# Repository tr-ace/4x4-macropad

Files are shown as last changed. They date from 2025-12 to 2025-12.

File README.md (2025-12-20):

# 4x4 Macropad

The Macropad is a 16-key keyboard with assignable keys via Python and the KMK library. The microcontroller uses the CircuitPython firmware.

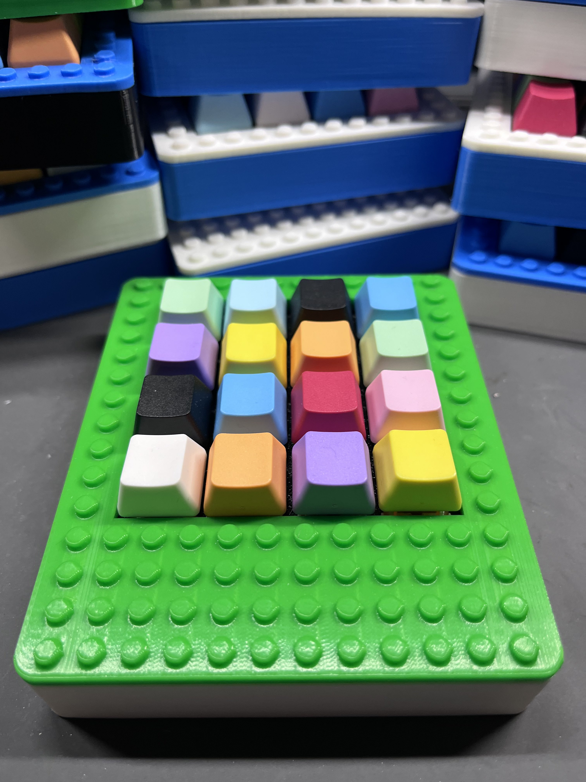
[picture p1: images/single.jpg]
Macropad


## Usage

Plug the Macropad into your PC with a USB C cable. Windows Explorer may open, since the CircuitPython firmware on the microcontroller may be detected as a mass storage device. You can close Windows Explorer, unless you'd like to customize the keymap.

## Default Keymap

> ℹ️ **Info**
> Row 1, Column 1 is the key closest to the USB C port)

| Row \ Col | Col 1 | Col 2 | Col 3 | Col 4 |
| --- | --- | --- | --- | --- |
| **Row 1** | Ctrl + A<br>(Select All) | Ctrl + C<br>(Copy) | Ctrl + V<br>(Paste) | Ctrl + S<br>(Save) |
| **Row 2** | Ctrl + Shift + M<br>(Teams Mute Mic) | Mute Speakers | Volume Down | Volume Up |
| **Row 3** | Win + M<br>(Open Mail) | Win + E<br>(Open File Explorer) | Ctrl + F<br>(Find) | Ctrl + H<br>(Replace) |
| **Row 4** | Ctrl + Z<br>(Undo) | Ctrl + Y<br>(Redo) | Win + Shift + S <br>(Snipping Tool) | Win + Tab<br>(Switch Windows) |

## Customizing the Keymap

To customize the keymap:

1. Plug in the Macropad via USB C cable
2. Open the CIRCUITPY drive inside of Windows Explorer
3. Open code.py inside of any IDE or Notepad.
4. Scroll down to this section where `keymap` list is defined
5. Change the key values assigned to each key, as needed
6. Save the updated code.py file
7. You might need to unplug, and replug the Macropad back into the PC for the changes to be detected

[See more documentation on KMK for more customization](https://github.com/KMKfw/kmk_firmware/blob/main/docs/en/Getting_Started.md)

## Parts List

- The case is 3D printable comprised of 3 pieces, designed in Fusion 360, and printed on a BambuLabs P1S printer. They are printed in various colors of PLA filament. There are no screws, as everything is press-fit. See [./Code/](./Code/) for the STL files
- The PCB was designed in KiCad, and manufactured by PCBWay.com. See [./KiCad/](./KiCad/) for the KiCad files.
- [Linear MX Switches](https://www.amazon.com/dp/B0D7QW8SQ9?ref=ppx_yo2ov_dt_b_fed_asin_title&th=1)
- [Blank, Rainbow Mixed Keycaps](https://www.amazon.com/dp/B0CQ2WGP2N?ref=ppx_yo2ov_dt_b_fed_asin_title&th=1)
- [1N4148 Diodes](https://www.amazon.com/dp/B00N1ZKU7E?ref=ppx_yo2ov_dt_b_fed_asin_title)
- [Seeed nRF52840 Sense microcontrollers](https://www.amazon.com/dp/B0DJ6PZGB7?ref=ppx_yo2ov_dt_b_fed_asin_title&th=1)

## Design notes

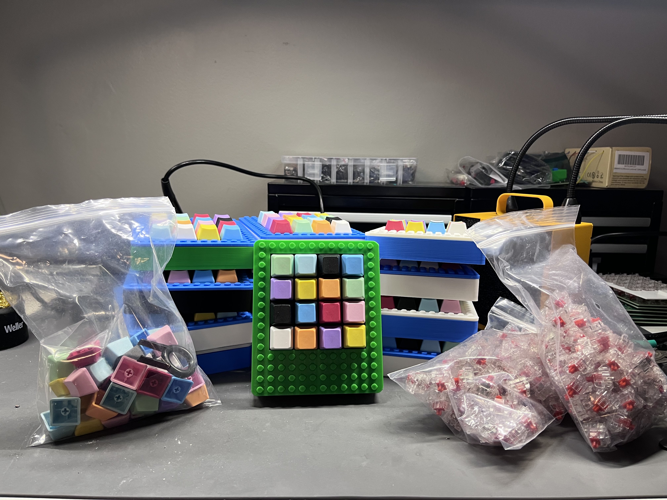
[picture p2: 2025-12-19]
images/multiple.jpg

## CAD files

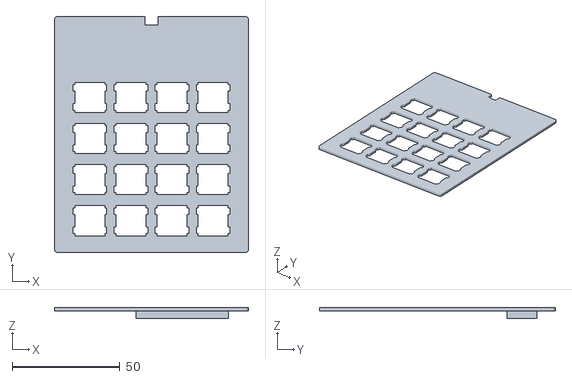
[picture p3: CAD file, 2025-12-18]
STLs/Key Plate.stl
90.0 x 109.4 x 4.90

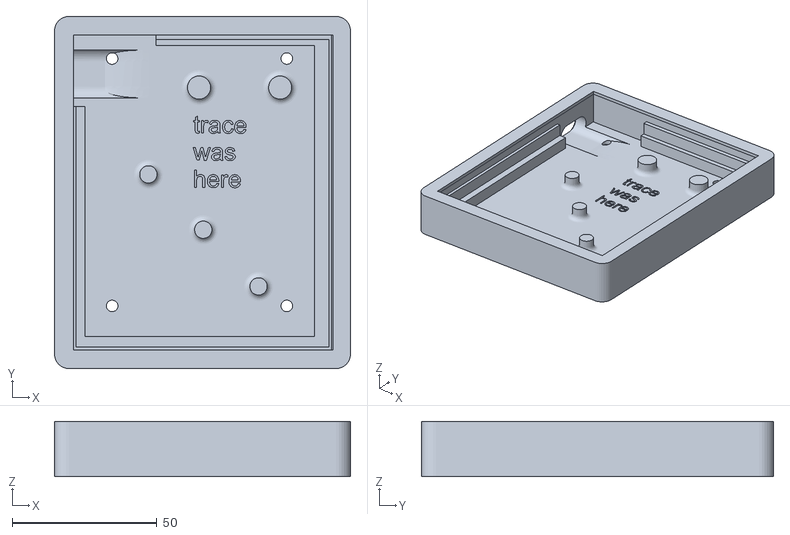
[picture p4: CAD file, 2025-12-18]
STLs/Case.stl
102.2 x 121.6 x 19.0

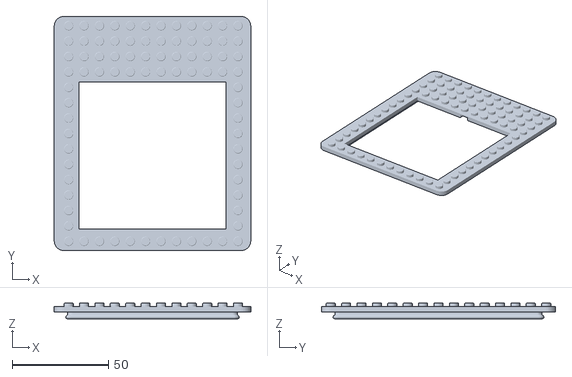
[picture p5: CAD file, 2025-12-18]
STLs/Top Plate.stl
102.2 x 121.6 x 8.20

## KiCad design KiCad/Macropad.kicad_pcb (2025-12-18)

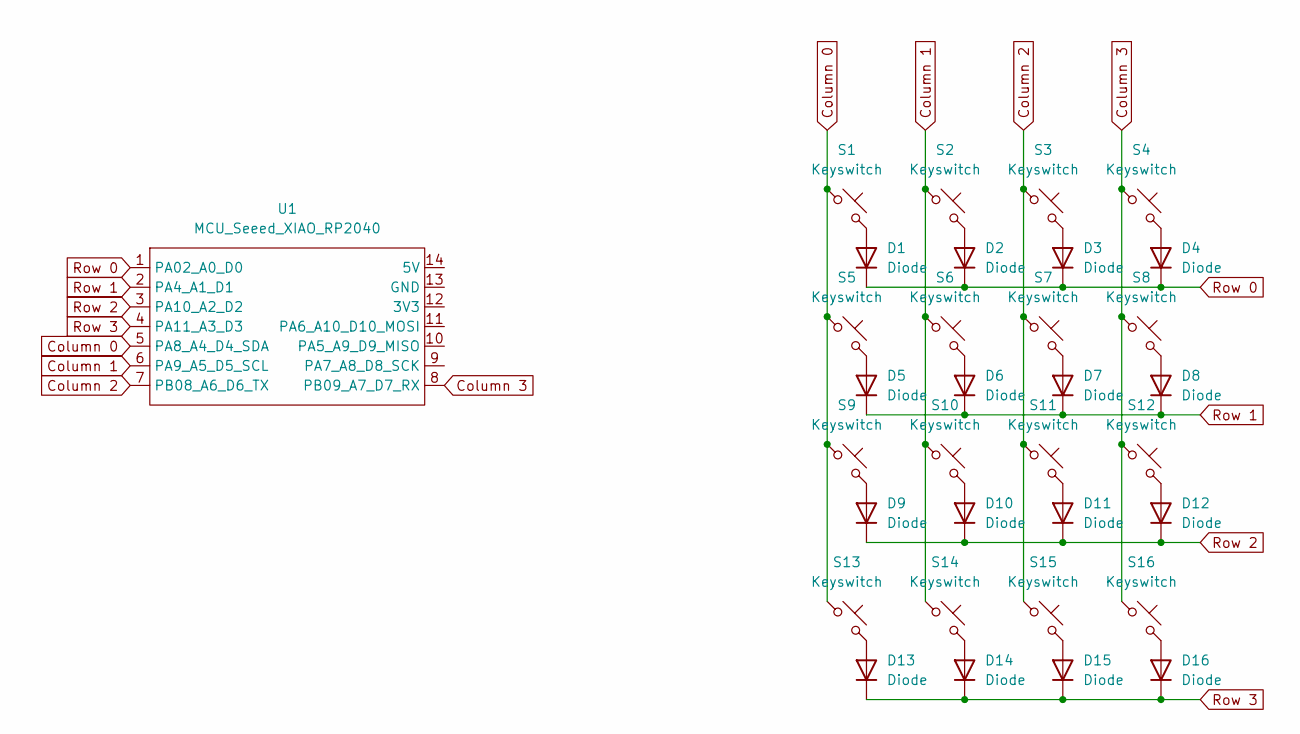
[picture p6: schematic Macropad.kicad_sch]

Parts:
D1, D2, D3, D4, D5, D6, D7, D8, D9, D10, D11, D12, D13, D14, D15, D16: Diode; Diode_DO-35
S1, S2, S3, S4, S5, S6, S7, S8, S9, S10, S11, S12, S13, S14, S15, S16: Keyswitch; MX_PCB_1.00u
U1: MCU_Seeed_XIAO_RP2040; Seeed_XIAO_RP2040

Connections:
Column 0: S1.1, S5.1, S9.1, S13.1, U1.5 (PA8_A4_D4_SDA)
Column 1: S2.1, S6.1, S10.1, S14.1, U1.6 (PA9_A5_D5_SCL)
Column 2: S3.1, S7.1, S11.1, S15.1, U1.7 (PB08_A6_D6_TX)
Column 3: S4.1, S8.1, S12.1, S16.1, U1.8 (PB09_A7_D7_RX)
unnamed: D1.2 (A), S1.2
unnamed: D2.2 (A), S2.2
unnamed: D3.2 (A), S3.2
unnamed: D4.2 (A), S4.2
unnamed: D5.2 (A), S5.2
unnamed: D6.2 (A), S6.2
unnamed: D7.2 (A), S7.2
unnamed: D8.2 (A), S8.2
unnamed: D9.2 (A), S9.2
unnamed: D10.2 (A), S10.2
unnamed: D11.2 (A), S11.2
unnamed: D12.2 (A), S12.2
unnamed: D13.2 (A), S13.2
unnamed: D14.2 (A), S14.2
unnamed: D15.2 (A), S15.2
unnamed: D16.2 (A), S16.2
Row 0: D1.1 (K), D2.1 (K), D3.1 (K), D4.1 (K), U1.1 (PA02_A0_D0)
Row 1: D5.1 (K), D6.1 (K), D7.1 (K), D8.1 (K), U1.2 (PA4_A1_D1)
Row 2: D9.1 (K), D10.1 (K), D11.1 (K), D12.1 (K), U1.3 (PA10_A2_D2)
Row 3: D13.1 (K), D14.1 (K), D15.1 (K), D16.1 (K), U1.4 (PA11_A3_D3)

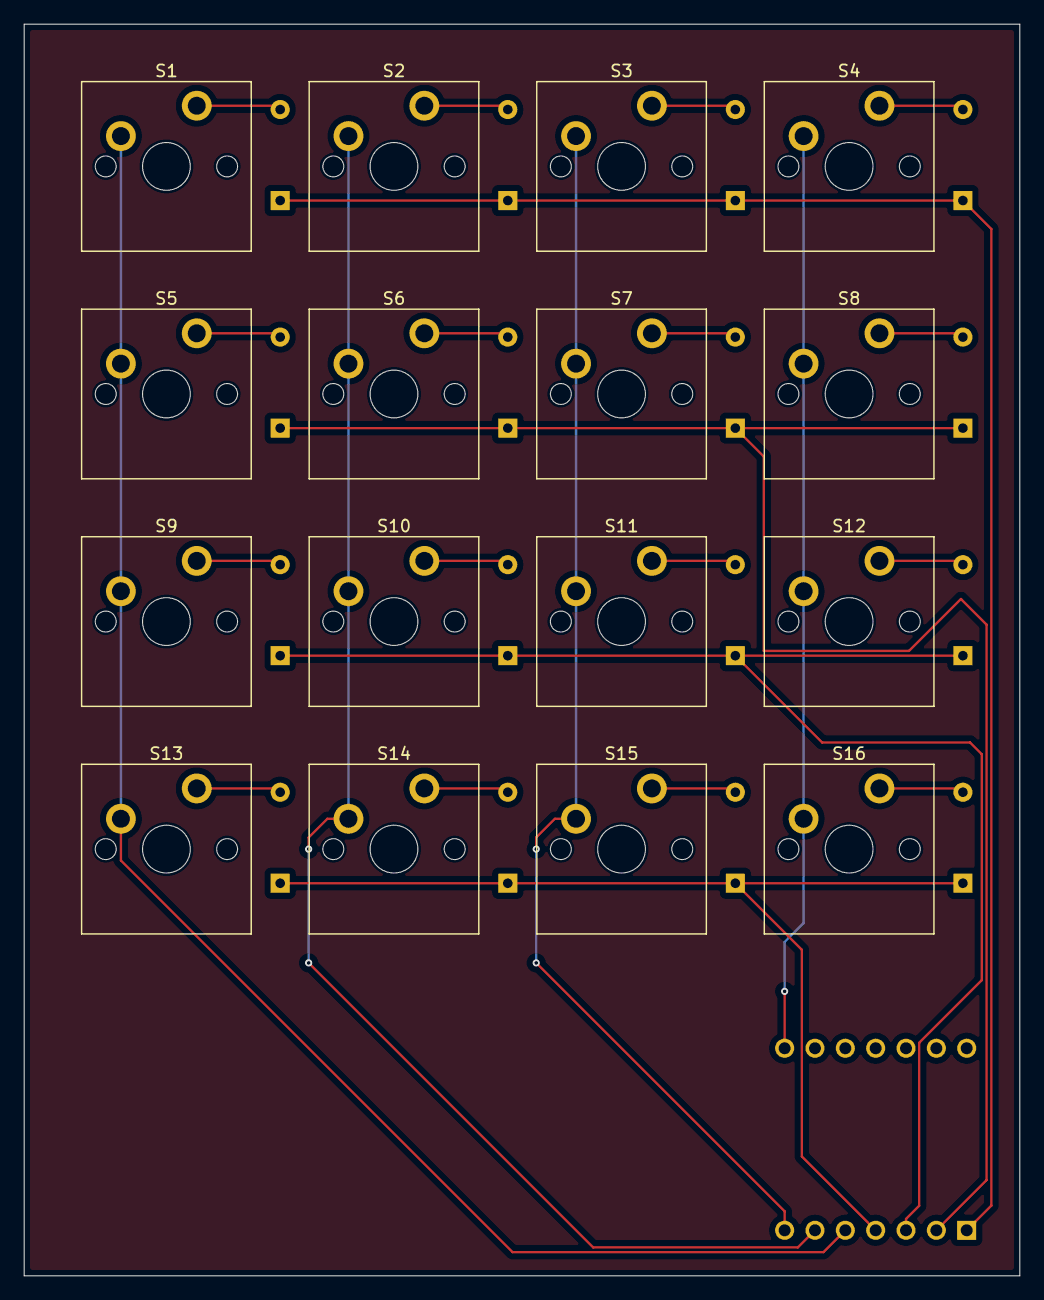
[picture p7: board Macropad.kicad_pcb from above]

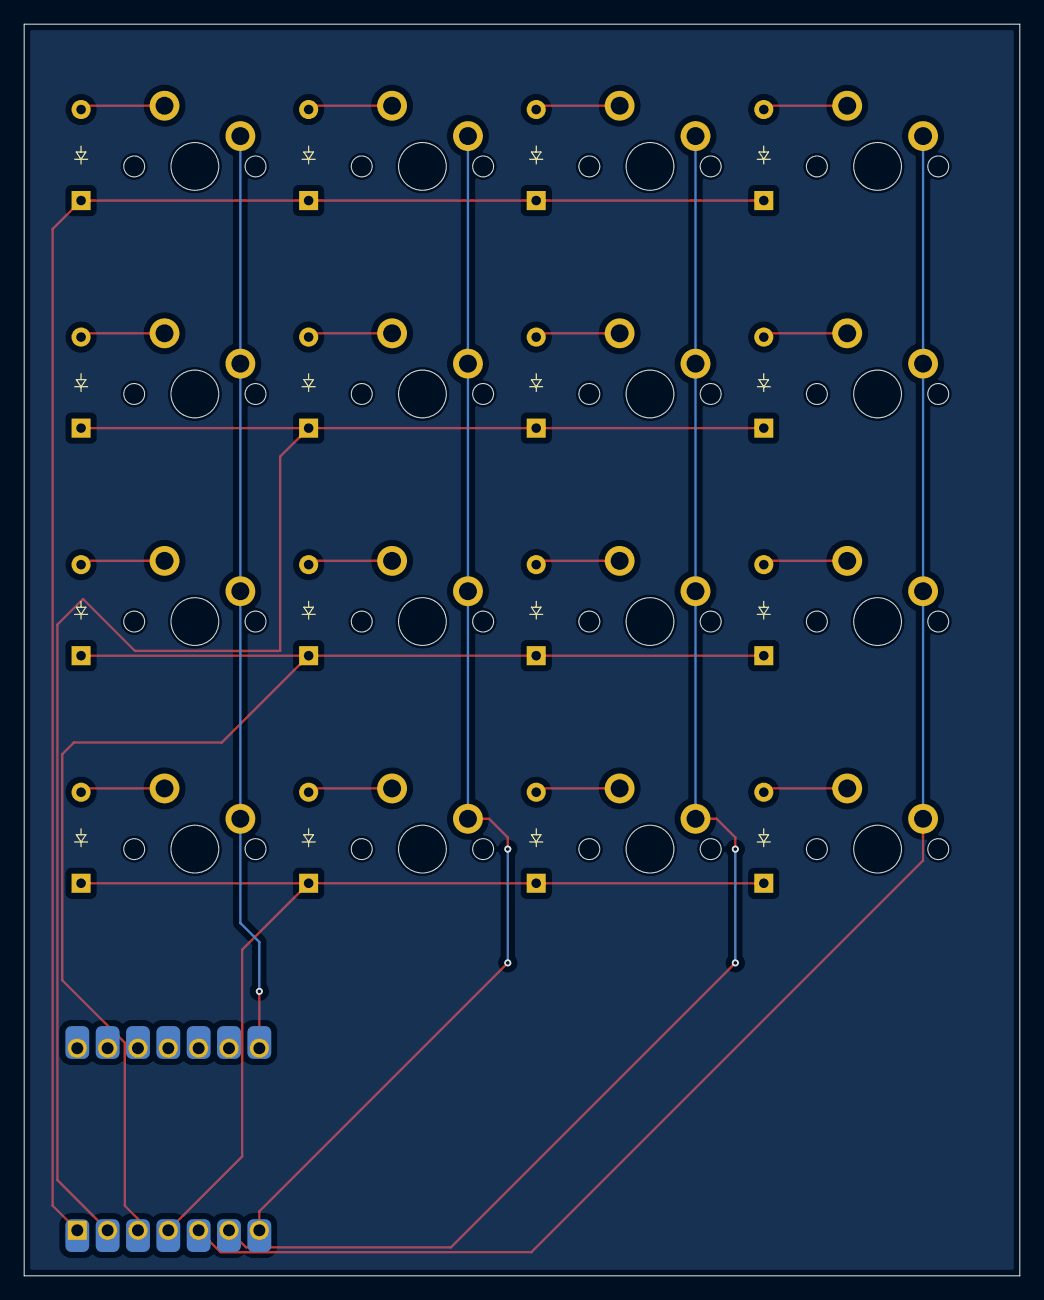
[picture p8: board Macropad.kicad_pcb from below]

Board: 2 copper layers, 83.3 x 104.8 mm, 33 parts (17 on the bottom side), 24 nets.

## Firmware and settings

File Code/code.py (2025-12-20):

# https://github.com/tr-ace/4x4-macropad

import board

from kmk.kmk_keyboard import KMKKeyboard
from kmk.keys import KC
from kmk.scanners import DiodeOrientation
from kmk.extensions.media_keys import MediaKeys

keyboard = KMKKeyboard()

keyboard.extensions.append(MediaKeys())

# Matrix Pins
keyboard.row_pins = (
    board.D0,  # Row 1
    board.D1,  # Row 2
    board.D2,  # Row 3
    board.D3,  # Row 4
)

keyboard.col_pins = (
    board.D4,  # Col 1
    board.D5,  # Col 2
    board.D6,  # Col 3
    board.D7,  # Col 4
)
keyboard.diode_orientation = DiodeOrientation.COL2ROW


# Map macro keys below (Col 1 / Row 1 is the key closest to the USB C port)
keymap = [
        # Col 1,                          Col 2,            Col 3,                         Col 4
        KC.LCTL(KC.Z),                    KC.LCTL(KC.Y),     KC.LGUI(KC.LSFT(KC.S)),       KC.LGUI(KC.TAB),   # Row 4

        KC.LGUI(KC.M),                    KC.LGUI(KC.E),     KC.LCTL(KC.F),                KC.LCTL(KC.H),     # Row 3

        KC.LCTL(KC.LSFT(KC.M)),           KC.MUTE,           KC.AUDIO_VOL_DOWN,            KC.AUDIO_VOL_UP,   # Row 2

        KC.LCTL(KC.A),                    KC.LCTL(KC.C),     KC.LCTL(KC.V),                KC.LCTL(KC.S),     # Row 1
]

formatted_keymap = []

# Reverse keymap so it logically lines up with the physical keys
for i in range(0, len(keymap), 4):
    current_group = keymap[i:i + 4]
    formatted_keymap.extend(list(reversed(current_group)))


keyboard.keymap = [formatted_keymap]


if __name__ == '__main__':
    keyboard.go()

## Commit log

2025-12-18 Rename STLs
    [Key Plate.stl, Top Plate.stl]
2025-12-20 Fix macro keys and README
    [code.py]
